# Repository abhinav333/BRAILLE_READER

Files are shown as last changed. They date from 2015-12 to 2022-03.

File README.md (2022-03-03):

# Braille e-book reader

Refer work *A. Kulkarni and K. Bhurchandi, "Low Cost E-Book Reading Device for Blind People," 2015 International Conference on Computing Communication Control and Automation, 2015, pp. 516-520, doi: 10.1109/ICCUBEA.2015.106.*

Program, schematics and images<br />
File description:<br />
**braillecode.c** - Lookup table for mapping of aplhanumeric characters to respective braille characters<br />
**buzzer.c** - Contains modules to generate variety of buzzer notifications<br />
**lcd.c** - Consists of lcd display functions. Used only in test mode.<br />
**main.c** - Main program<br />
**mmc.c** - PetitFATFS library: MMC Disk image control modules<br />
**pff.c** - PetitFATFS library: High level SD Card control modules<br />
**pffconf.h** - PetitFATFS library: Version and configuration file<br />
**spi.h** - Low level SPI access functions<br />
**Schematics** - Eagle PCB design files<br />
**test cell** - Contains debug modules for each braille cell<br />
**Hardware** - Device images<br />

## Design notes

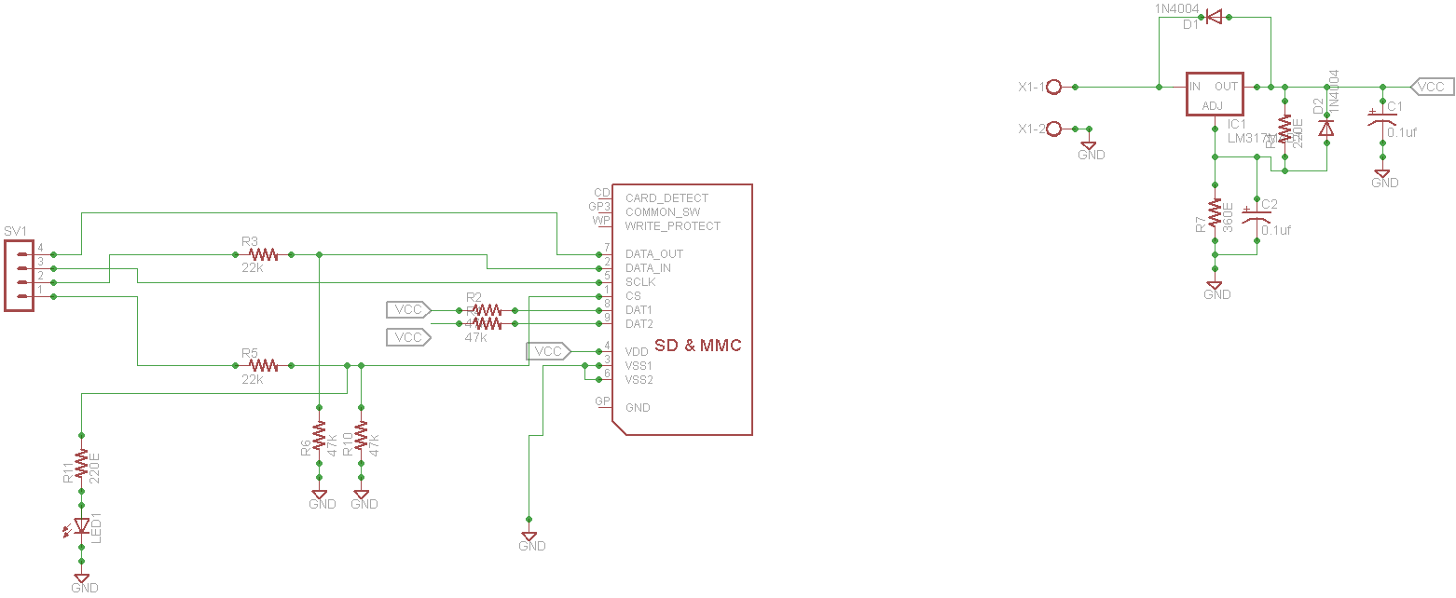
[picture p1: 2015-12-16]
schematics/sdunitckt.png

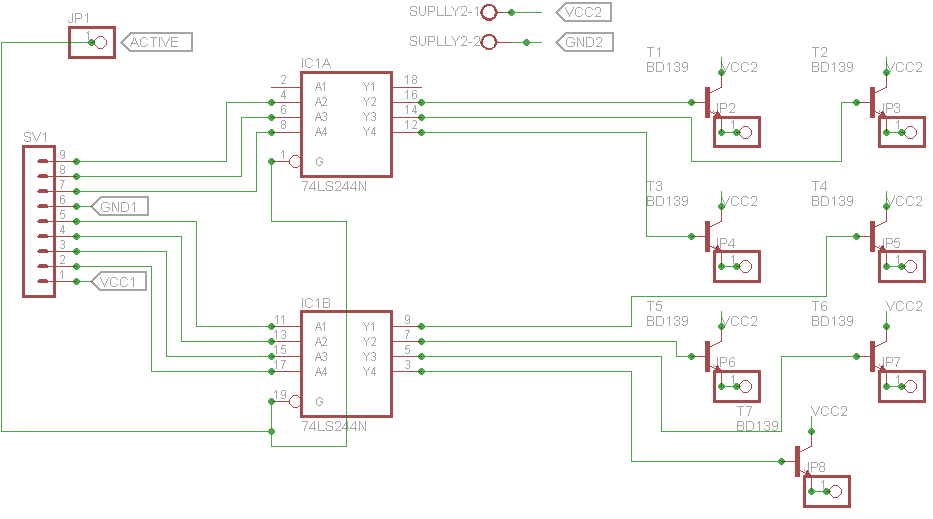
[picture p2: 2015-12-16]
schematics/driverckt.png

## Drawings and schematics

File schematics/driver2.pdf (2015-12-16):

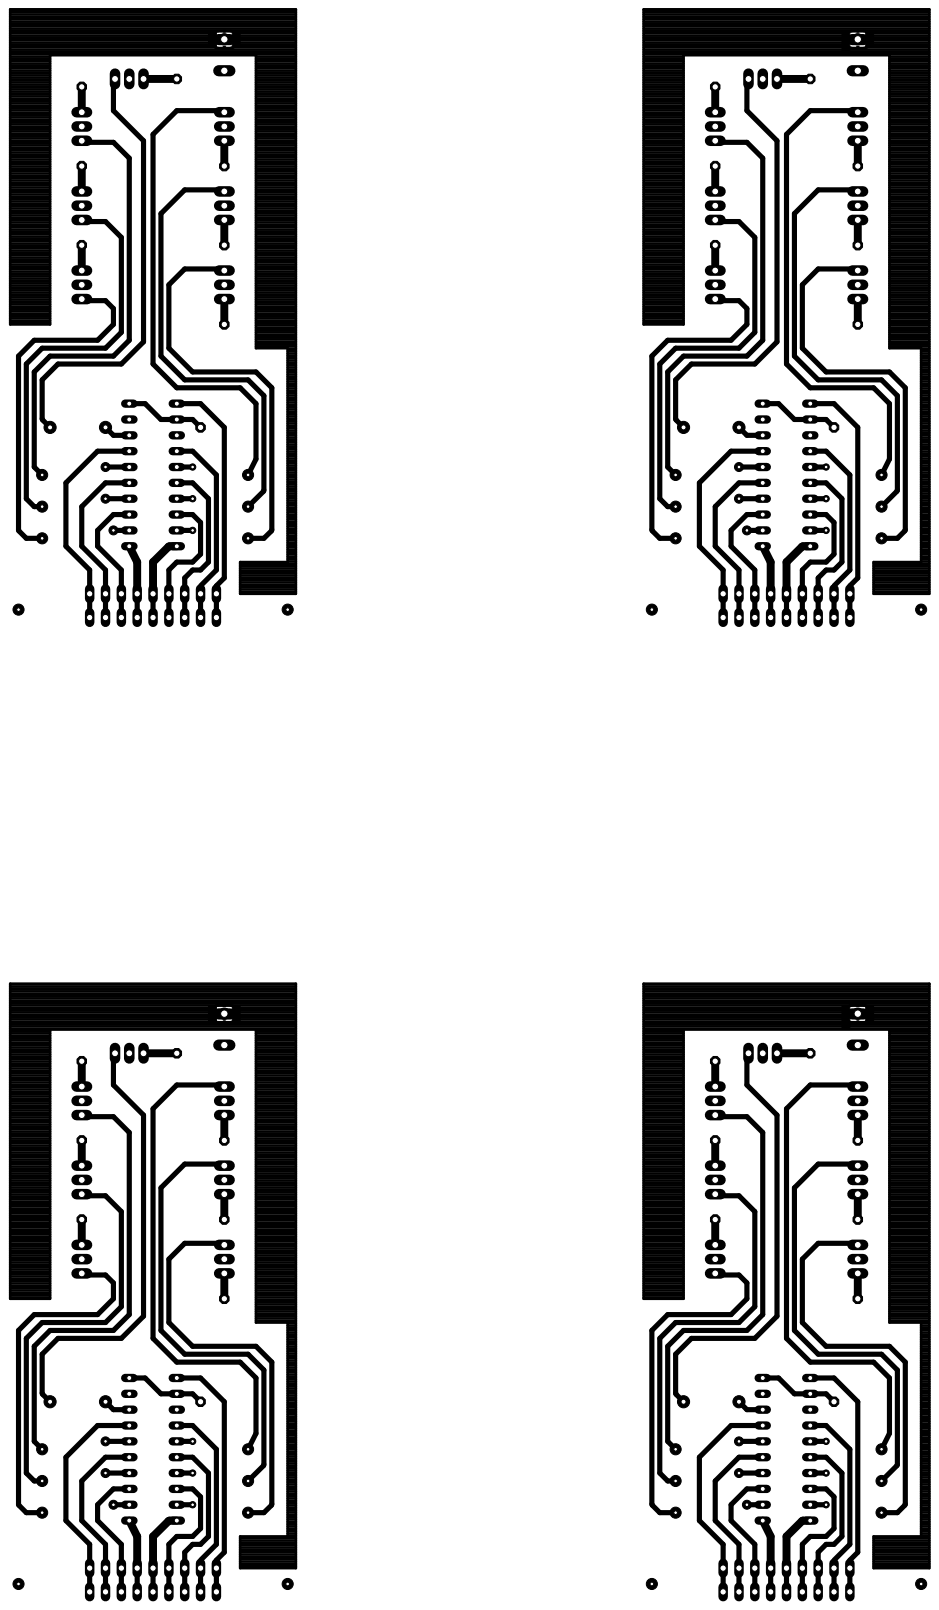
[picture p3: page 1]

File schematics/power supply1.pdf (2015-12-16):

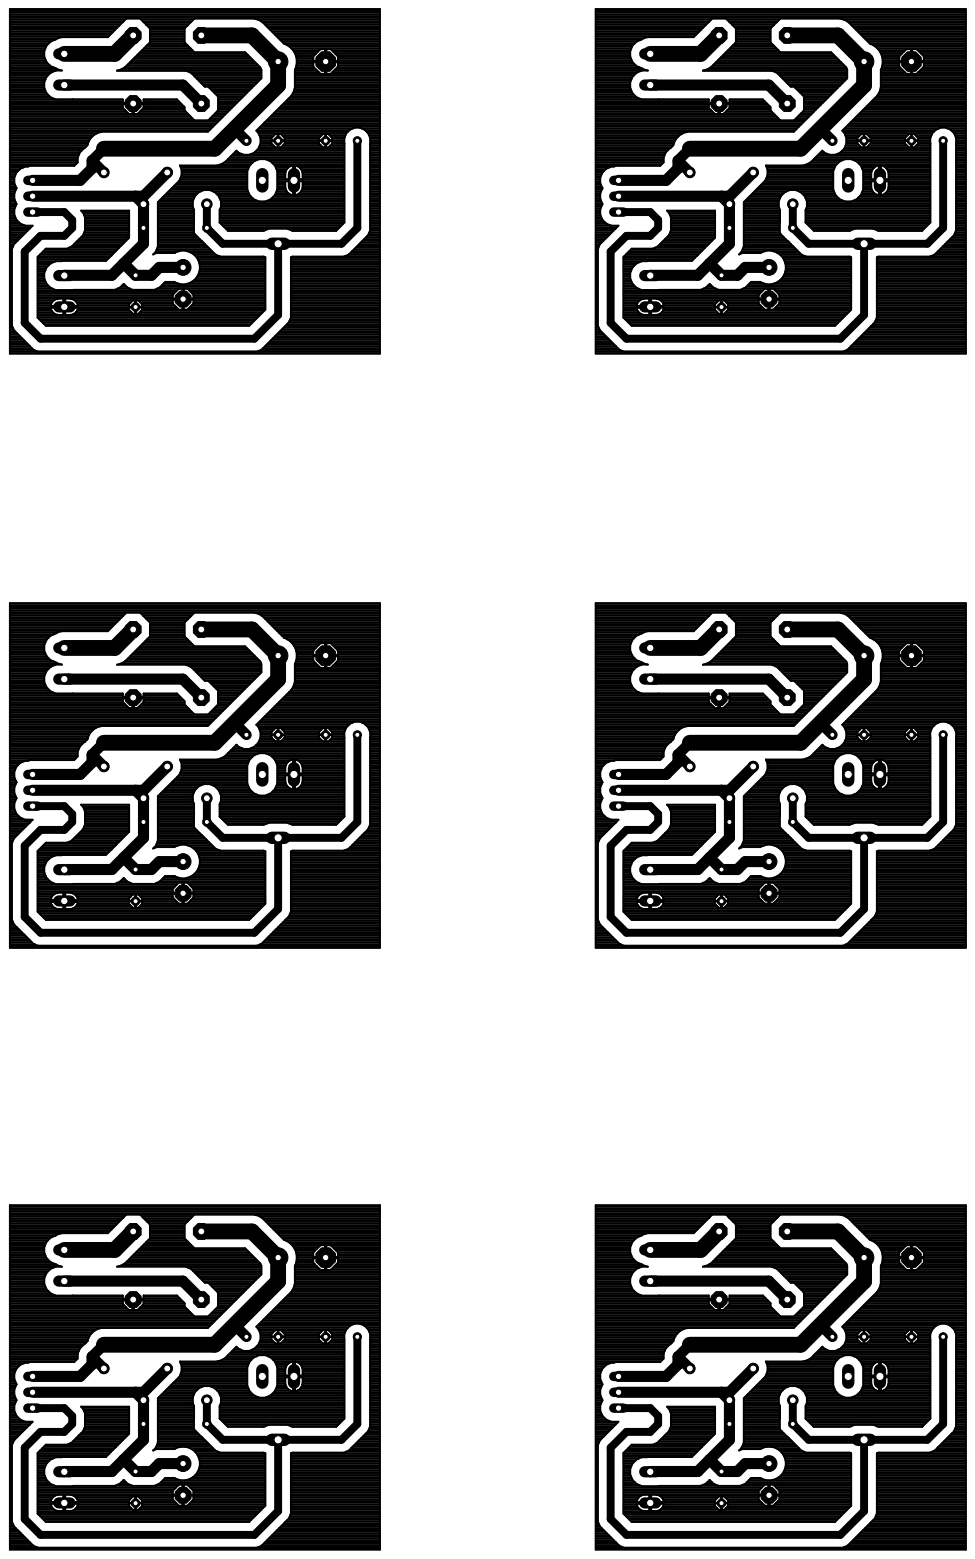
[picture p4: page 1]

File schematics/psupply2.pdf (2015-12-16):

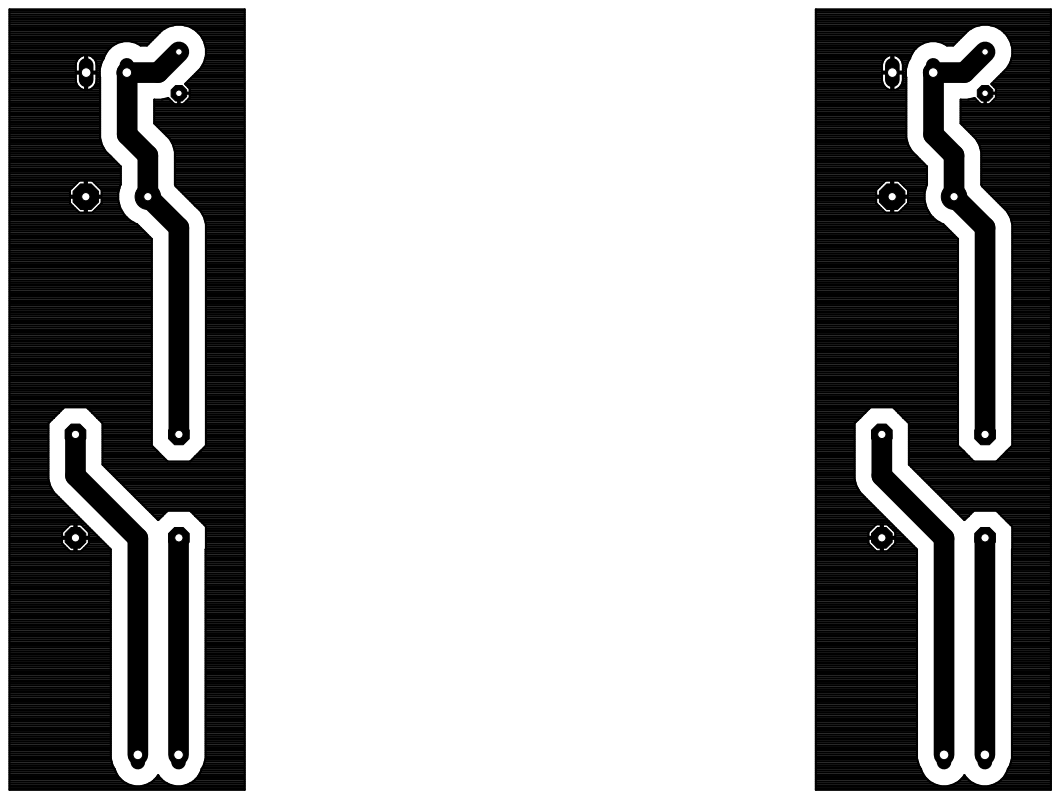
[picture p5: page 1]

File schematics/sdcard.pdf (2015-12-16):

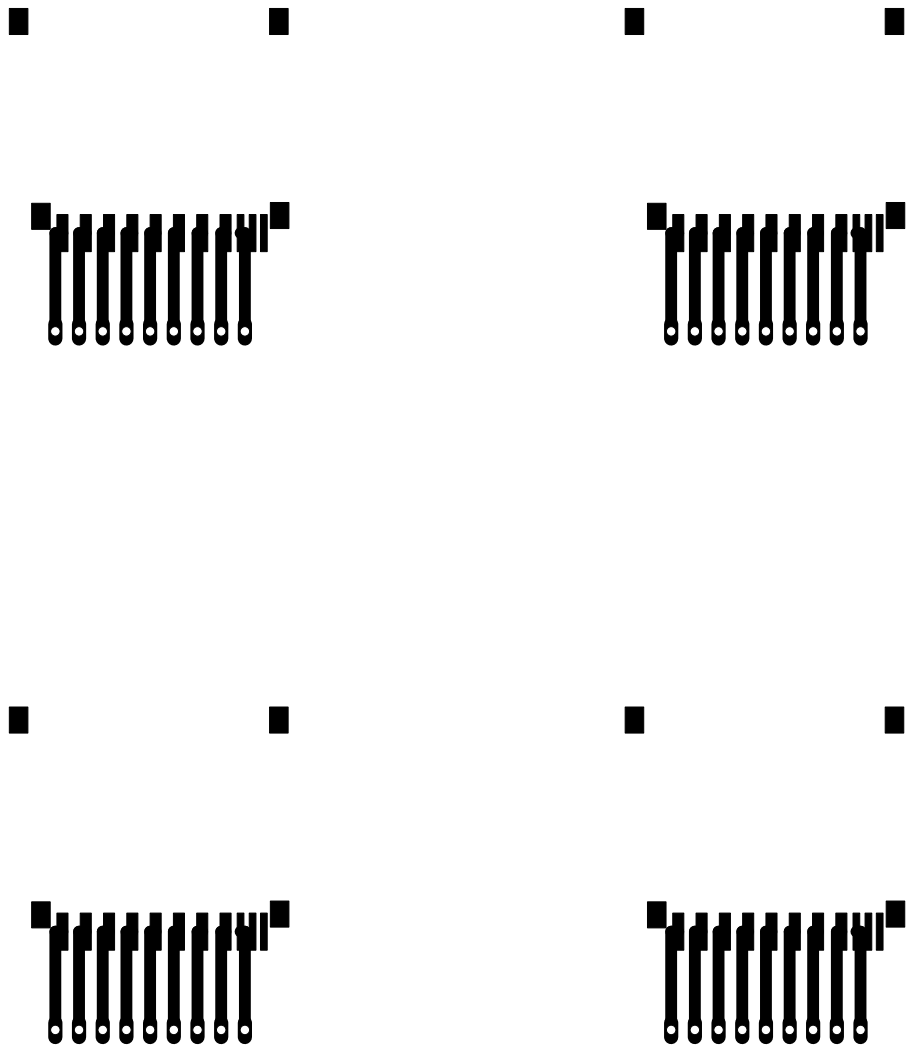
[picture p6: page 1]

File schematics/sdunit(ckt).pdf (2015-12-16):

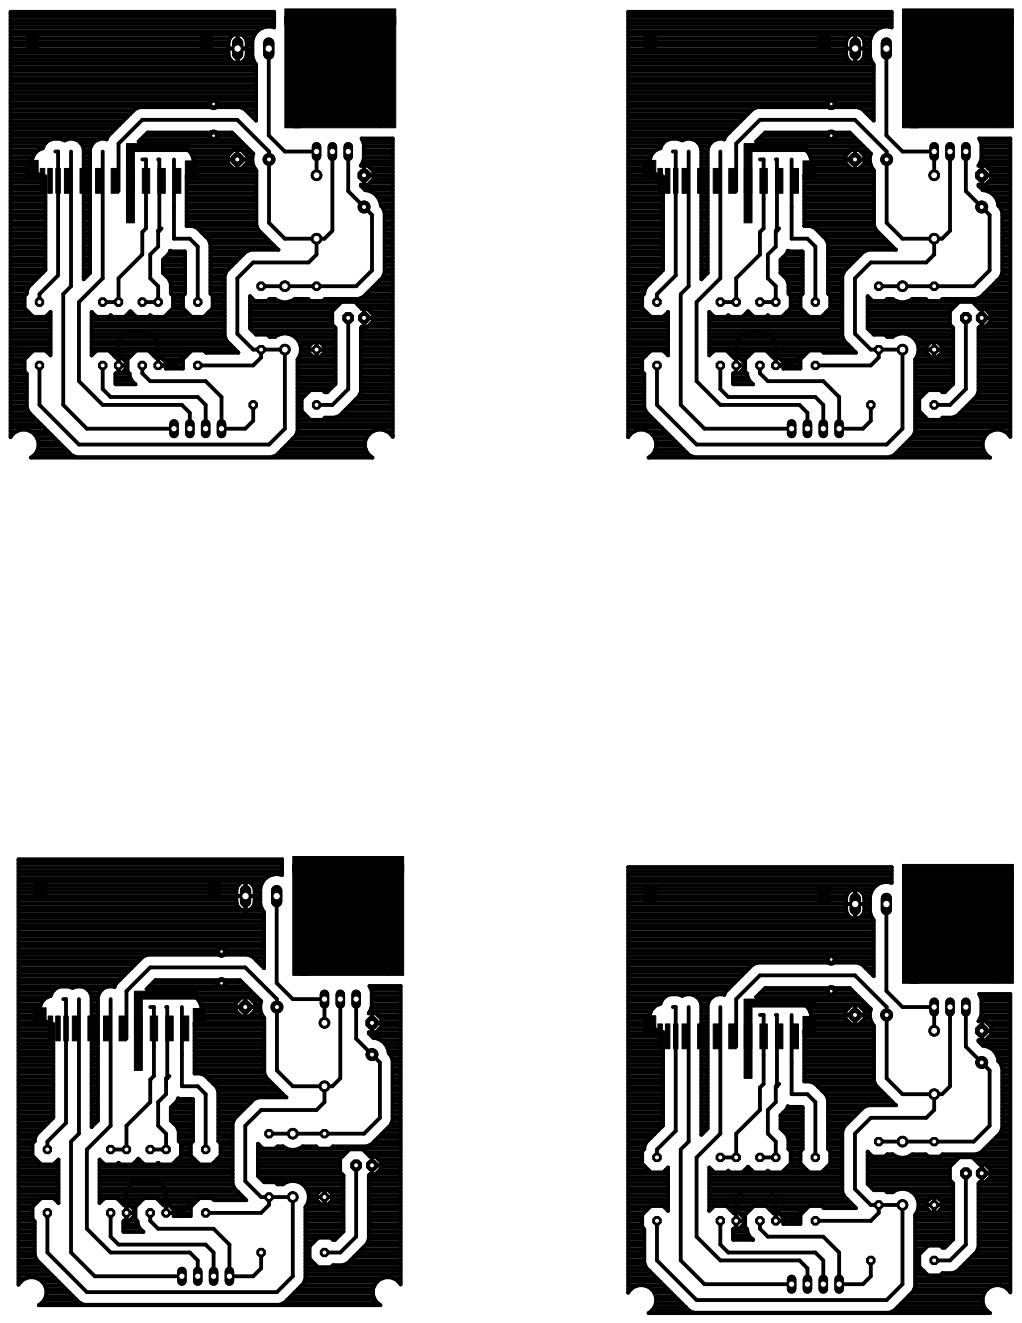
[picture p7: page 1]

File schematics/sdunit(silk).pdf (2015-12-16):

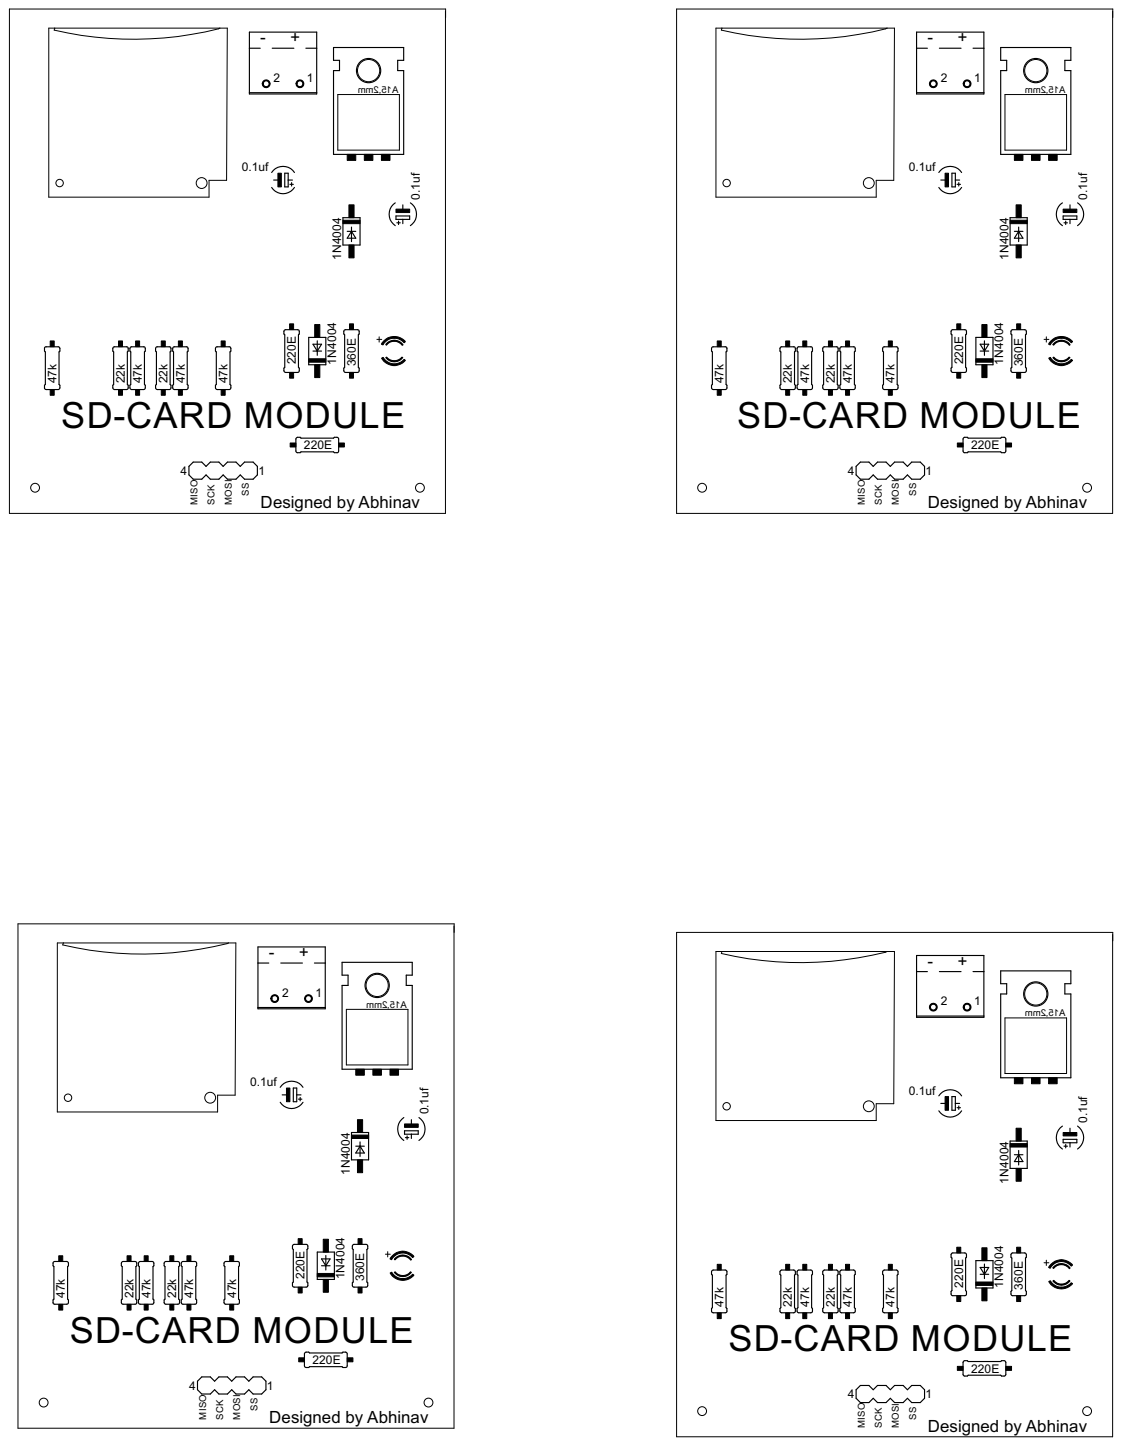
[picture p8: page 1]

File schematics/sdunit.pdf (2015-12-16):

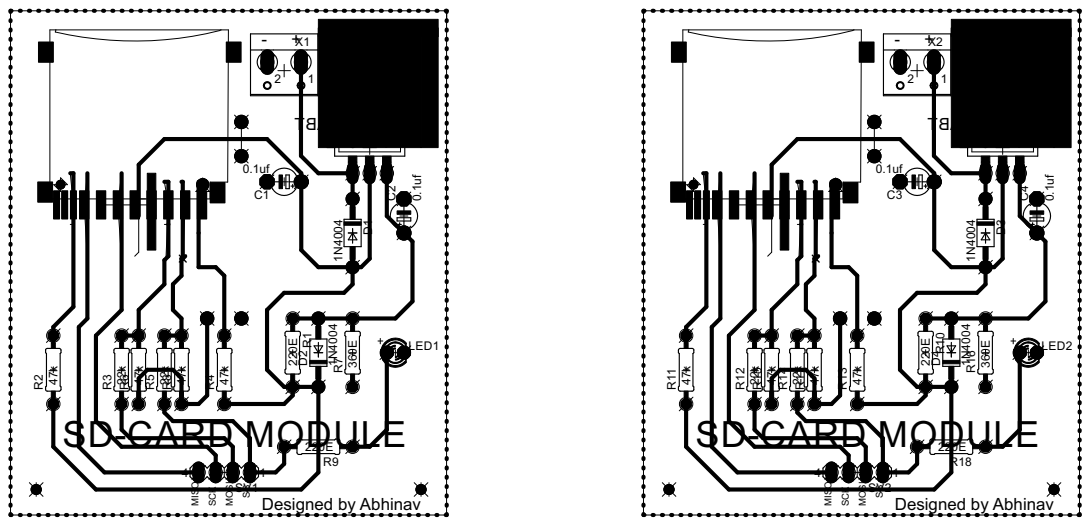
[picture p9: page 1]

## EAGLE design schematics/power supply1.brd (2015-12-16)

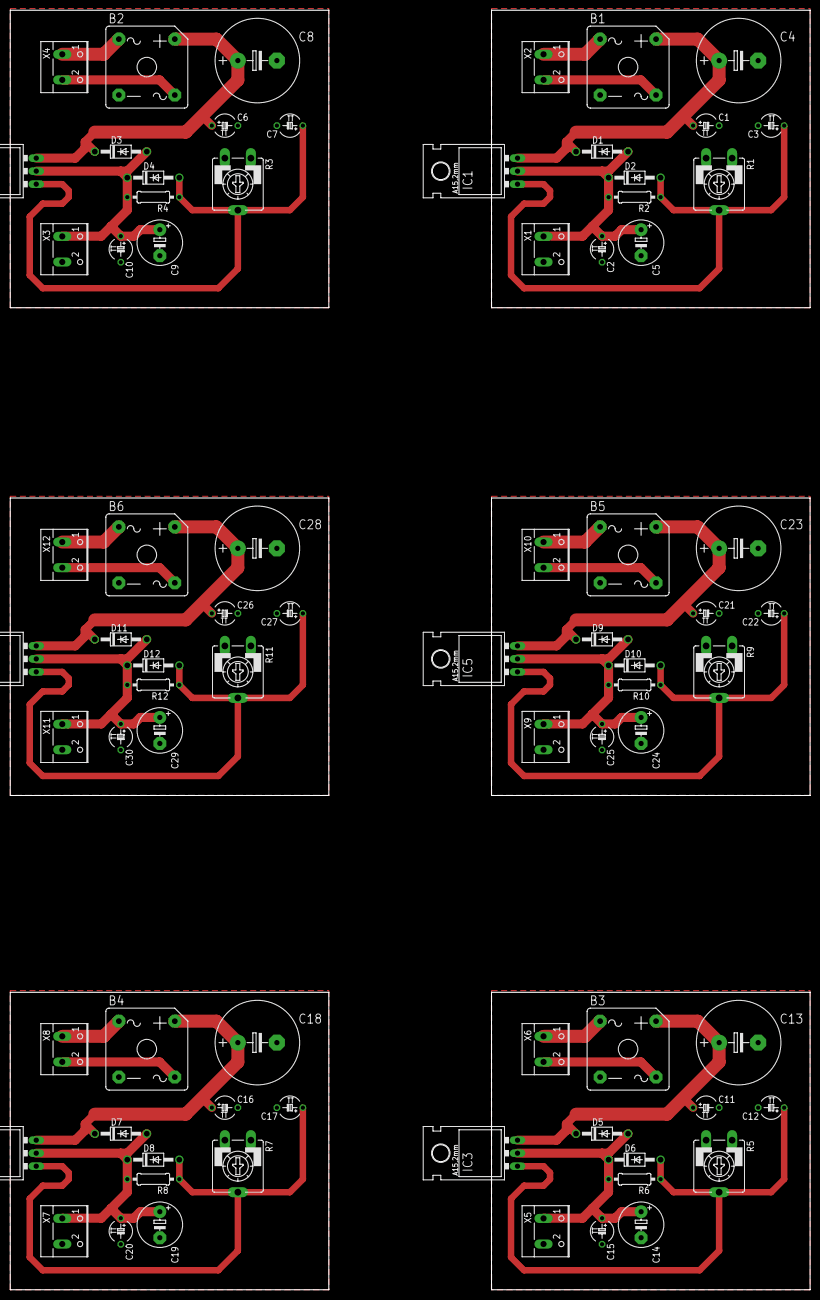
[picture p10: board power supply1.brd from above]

Board: 2 copper layers, 156.2 x 249.9 mm, 78 parts (0 on the bottom side), 36 nets.

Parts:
B1, B2, B3, B4, B5, B6: GBPC1
C1, C2, C3, C6, C7, C10, C11, C12, C15, C16, C17, C20, C21, C22, C25, C26, C27, C30: 0.1uF; TAP5-45
C4, C8, C13, C18, C23, C28: E7,5-16
C5, C9, C14, C19, C24, C29: E5-8,5
D1, D2, D3, D4, D5, D6, D7, D8, D9, D10, D11, D12: 1N4004; DO41-10
IC1, IC2, IC3, IC4, IC5, IC6: LM317MBT; TO220L1
R1, R3, R5, R7, R9, R11: CA9V
R2, R4, R6, R8, R10, R12: 120R; 0207/10
X1, X2, X3, X4, X5, X6, X7, X8, X9, X10, X11, X12: W237-102

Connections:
AGND: B1.-, C1.-, C2.-, C3.-, C4.-, C5.-, R1.A, X1.2
AGND1: B2.-, C6.-, C7.-, C8.-, C9.-, C10.-, R3.A, X3.2
AGND2: B3.-, C11.-, C12.-, C13.-, C14.-, C15.-, R5.A, X5.2
AGND3: B4.-, C16.-, C17.-, C18.-, C19.-, C20.-, R7.A, X7.2
AGND4: B5.-, C21.-, C22.-, C23.-, C24.-, C25.-, R9.A, X9.2
AGND5: B6.-, C26.-, C27.-, C28.-, C29.-, C30.-, R11.A, X11.2
unnamed: B1.+, C1.+, C4.+, D1.C, IC1.3
unnamed: C2.+, C5.+, D1.A, D2.C, IC1.2, R2.2, X1.1
unnamed: C3.+, D2.A, IC1.1, R1.S, R2.1
unnamed: B2.+, C6.+, C8.+, D3.C, IC2.3
unnamed: C9.+, C10.+, D3.A, D4.C, IC2.2, R4.2, X3.1
unnamed: B1.AC1, X2.1
unnamed: B1.AC2, X2.2
unnamed: C7.+, D4.A, IC2.1, R3.S, R4.1
unnamed: B2.AC1, X4.1
unnamed: B2.AC2, X4.2
unnamed: B3.+, C11.+, C13.+, D5.C, IC3.3
unnamed: C14.+, C15.+, D5.A, D6.C, IC3.2, R6.2, X5.1
unnamed: C12.+, D6.A, IC3.1, R5.S, R6.1
unnamed: B3.AC1, X6.1
unnamed: B3.AC2, X6.2
unnamed: B4.+, C16.+, C18.+, D7.C, IC4.3
unnamed: C19.+, C20.+, D7.A, D8.C, IC4.2, R8.2, X7.1
unnamed: C17.+, D8.A, IC4.1, R7.S, R8.1
unnamed: B4.AC1, X8.1
unnamed: B4.AC2, X8.2
unnamed: B5.+, C21.+, C23.+, D9.C, IC5.3
unnamed: C24.+, C25.+, D9.A, D10.C, IC5.2, R10.2, X9.1
unnamed: C22.+, D10.A, IC5.1, R9.S, R10.1
unnamed: B5.AC1, X10.1
unnamed: B5.AC2, X10.2
unnamed: B6.+, C26.+, C28.+, D11.C, IC6.3
unnamed: C29.+, C30.+, D11.A, D12.C, IC6.2, R12.2, X11.1
unnamed: C27.+, D12.A, IC6.1, R11.S, R12.1
unnamed: B6.AC1, X12.1
unnamed: B6.AC2, X12.2

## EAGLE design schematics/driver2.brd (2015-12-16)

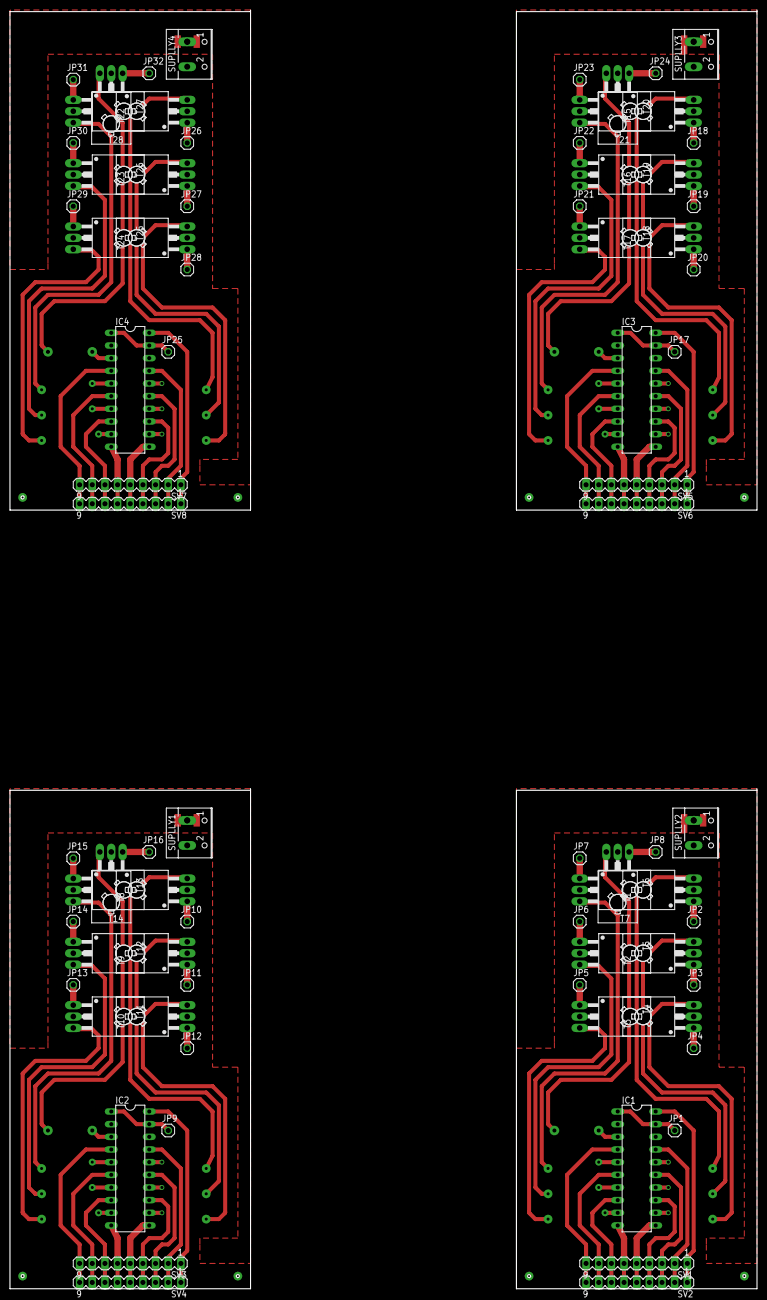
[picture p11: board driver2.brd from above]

Board: 2 copper layers, 149.9 x 256.5 mm, 76 parts (0 on the bottom side), 96 nets.

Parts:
IC1, IC2, IC3, IC4: 74LS244N; DIL20
JP1, JP2, JP3, JP4, JP5, JP6, JP7, JP8, JP9, JP10, JP11, JP12, JP13, JP14, JP15, JP16, JP17, JP18, JP19, JP20, JP21, JP22, JP23, JP24, JP25, JP26, JP27, JP28, JP29, JP30, JP31, JP32: 1X01
SUPLLY1, SUPLLY2, SUPLLY3, SUPLLY4: W237-102
SV1, SV2, SV3, SV4, SV5, SV6, SV7, SV8: MA09-1
T1, T2, T3, T4, T5, T6, T7, T8, T9, T10, T11, T12, T13, T14, T15, T16, T17, T18, T19, T20, T21, T22, T23, T24, T25, T26, T27, T28: BD139; TO126

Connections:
ACTIVE: IC1.1, IC1.19, JP1.1
ACTIVE1: IC2.1, IC2.19, JP9.1
ACTIVE2: IC3.1, IC3.19, JP17.1
ACTIVE3: IC4.1, IC4.19, JP25.1
GND1: IC1.10, SV1.6, SV2.6
GND4: IC2.10, SV3.6, SV4.6
GND6: IC3.10, SV5.6, SV6.6
GND8: IC4.10, SV7.6, SV8.6
unnamed: IC1.4, SV1.9, SV2.9
unnamed: IC1.6, SV1.8, SV2.8
unnamed: IC1.8, SV1.7, SV2.7
unnamed: IC1.3, T7.3
unnamed: IC1.11, SV1.5, SV2.5
unnamed: IC1.13, SV1.4, SV2.4
unnamed: IC1.16, T1.3
unnamed: JP2.1, T1.1
unnamed: IC1.14, T2.3
unnamed: IC1.12, T3.3
unnamed: IC1.15, SV1.3, SV2.3
unnamed: IC1.9, T4.3
unnamed: IC1.7, T5.3
unnamed: JP3.1, T2.1
unnamed: JP4.1, T3.1
unnamed: JP5.1, T4.1
unnamed: JP6.1, T5.1
unnamed: JP7.1, T6.1
unnamed: JP8.1, T7.1
unnamed: IC1.17, SV1.2, SV2.2
unnamed: IC2.12, T10.3
unnamed: JP10.1, T8.1
unnamed: JP11.1, T9.1
unnamed: JP12.1, T10.1
unnamed: JP13.1, T11.1
unnamed: JP14.1, T12.1
unnamed: JP15.1, T13.1
unnamed: JP16.1, T14.1
unnamed: IC2.3, T14.3
unnamed: IC2.16, T8.3
unnamed: IC2.14, T9.3
unnamed: IC2.9, T11.3
unnamed: IC2.7, T12.3
unnamed: IC2.4, SV3.9, SV4.9
unnamed: IC2.6, SV3.8, SV4.8
unnamed: IC2.8, SV3.7, SV4.7
unnamed: IC2.11, SV3.5, SV4.5
unnamed: IC2.13, SV3.4, SV4.4
unnamed: IC2.15, SV3.3, SV4.3
unnamed: IC2.17, SV3.2, SV4.2
unnamed: IC3.12, T17.3
unnamed: JP18.1, T15.1
unnamed: JP19.1, T16.1
unnamed: JP20.1, T17.1
unnamed: JP21.1, T18.1
unnamed: JP22.1, T19.1
unnamed: JP23.1, T20.1
unnamed: JP24.1, T21.1
unnamed: IC3.3, T21.3
unnamed: IC3.16, T15.3
unnamed: IC3.14, T16.3
unnamed: IC3.9, T18.3
unnamed: IC3.7, T19.3
unnamed: IC3.4, SV5.9, SV6.9
unnamed: IC3.6, SV5.8, SV6.8
unnamed: IC3.8, SV5.7, SV6.7
unnamed: IC3.11, SV5.5, SV6.5
unnamed: IC3.13, SV5.4, SV6.4
unnamed: IC3.15, SV5.3, SV6.3
unnamed: IC3.17, SV5.2, SV6.2
unnamed: IC4.12, T24.3
unnamed: JP26.1, T22.1
unnamed: JP27.1, T23.1
unnamed: JP28.1, T24.1
unnamed: JP29.1, T25.1
unnamed: JP30.1, T26.1
unnamed: JP31.1, T27.1
unnamed: JP32.1, T28.1
unnamed: IC4.3, T28.3
unnamed: IC4.16, T22.3
unnamed: IC4.14, T23.3
unnamed: IC4.9, T25.3
unnamed: IC4.7, T26.3
unnamed: IC4.4, SV7.9, SV8.9
unnamed: IC4.6, SV7.8, SV8.8
unnamed: IC4.8, SV7.7, SV8.7
unnamed: IC4.11, SV7.5, SV8.5
unnamed: IC4.13, SV7.4, SV8.4
unnamed: IC4.15, SV7.3, SV8.3
unnamed: IC4.17, SV7.2, SV8.2
VCC1: IC1.20, SV1.1, SV2.1
VCC2: SUPLLY2.1, T1.2, T2.2, T3.2
VCC3: SUPLLY1.1, T8.2, T9.2, T10.2
VCC4: IC2.20, SV3.1, SV4.1
VCC5: SUPLLY3.1, T15.2, T16.2, T17.2
VCC6: IC3.20, SV5.1, SV6.1
VCC7: SUPLLY4.1, T22.2, T23.2, T24.2
VCC8: IC4.20, SV7.1, SV8.1

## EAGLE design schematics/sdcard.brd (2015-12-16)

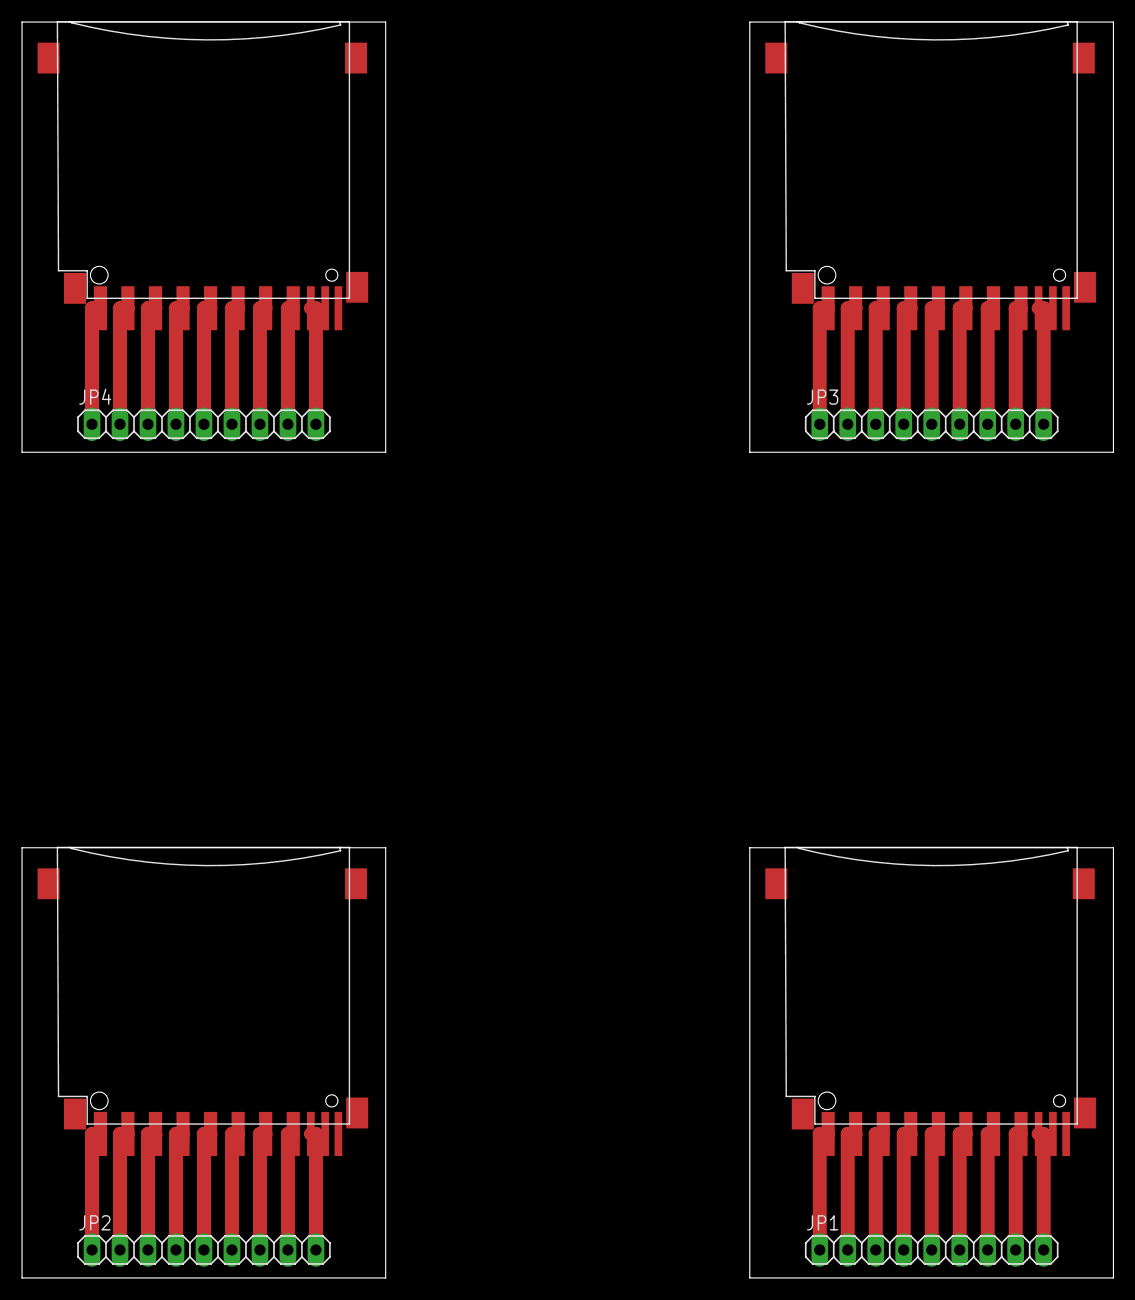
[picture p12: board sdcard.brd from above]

Board: 2 copper layers, 99.0 x 114.0 mm, 8 parts (0 on the bottom side), 36 nets.

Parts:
JP1, JP2, JP3, JP4: 1X09
U$1, U$2, U$3, U$4: SDMMC06132; 06132

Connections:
unnamed: JP1.2, U$1.1
unnamed: JP1.1, U$1.9
unnamed: JP1.3, U$1.2
unnamed: JP1.6, U$1.5
unnamed: JP1.8, U$1.7
unnamed: JP1.9, U$1.8
unnamed: JP2.2, U$2.1
unnamed: JP2.1, U$2.9
unnamed: JP2.3, U$2.2
unnamed: JP2.6, U$2.5
unnamed: JP2.8, U$2.7
unnamed: JP2.9, U$2.8
unnamed: JP3.2, U$3.1
unnamed: JP3.1, U$3.9
unnamed: JP3.3, U$3.2
unnamed: JP3.6, U$3.5
unnamed: JP3.8, U$3.7
unnamed: JP3.9, U$3.8
unnamed: JP4.2, U$4.1
unnamed: JP4.1, U$4.9
unnamed: JP4.3, U$4.2
unnamed: JP4.6, U$4.5
unnamed: JP4.8, U$4.7
unnamed: JP4.9, U$4.8
VDD: JP1.5, U$1.4
VDD1: JP2.5, U$2.4
VDD2: JP3.5, U$3.4
VDD3: JP4.5, U$4.4
VSS1: JP1.4, U$1.3
VSS2: JP1.7, U$1.6
VSS3: JP2.4, U$2.3
VSS4: JP2.7, U$2.6
VSS5: JP3.4, U$3.3
VSS6: JP3.7, U$3.6
VSS7: JP4.4, U$4.3
VSS8: JP4.7, U$4.6

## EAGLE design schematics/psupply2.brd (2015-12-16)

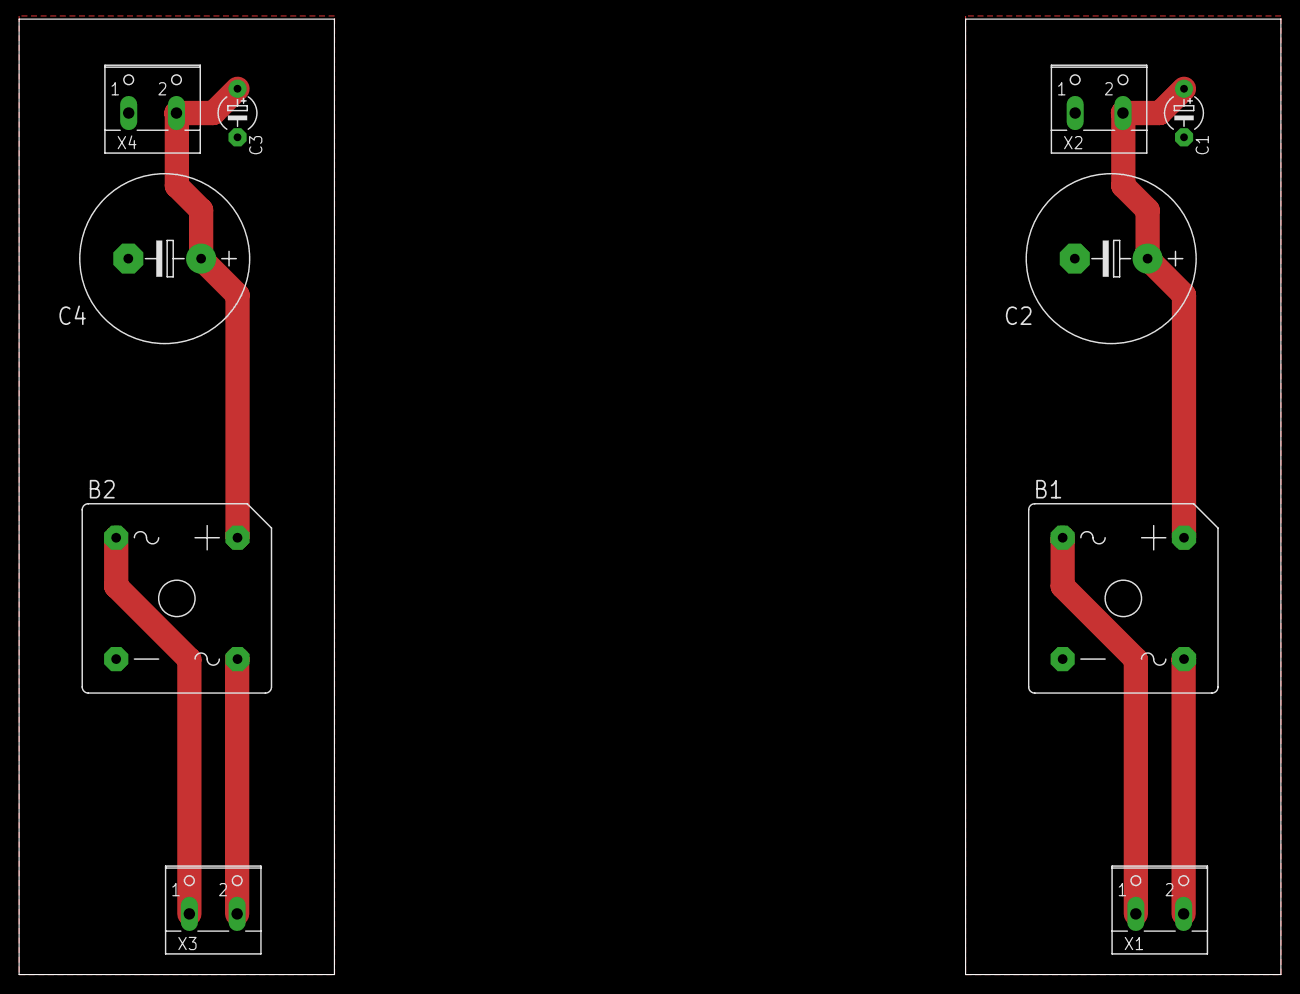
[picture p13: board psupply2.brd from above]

Board: 2 copper layers, 132.1 x 100.0 mm, 10 parts (0 on the bottom side), 8 nets.

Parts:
B1, B2: GBPC80X
C1, C3: E5-4
C2, C4: E7,5-18
X1, X2, X3, X4: W237-102

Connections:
GND: B1.-, C1.-, C2.-, X2.1
GND1: B2.-, C3.-, C4.-, X4.1
unnamed: B1.AC1, X1.1
unnamed: B1.AC2, X1.2
unnamed: B1.+, C1.+, C2.+, X2.2
unnamed: B2.AC1, X3.1
unnamed: B2.AC2, X3.2
unnamed: B2.+, C3.+, C4.+, X4.2

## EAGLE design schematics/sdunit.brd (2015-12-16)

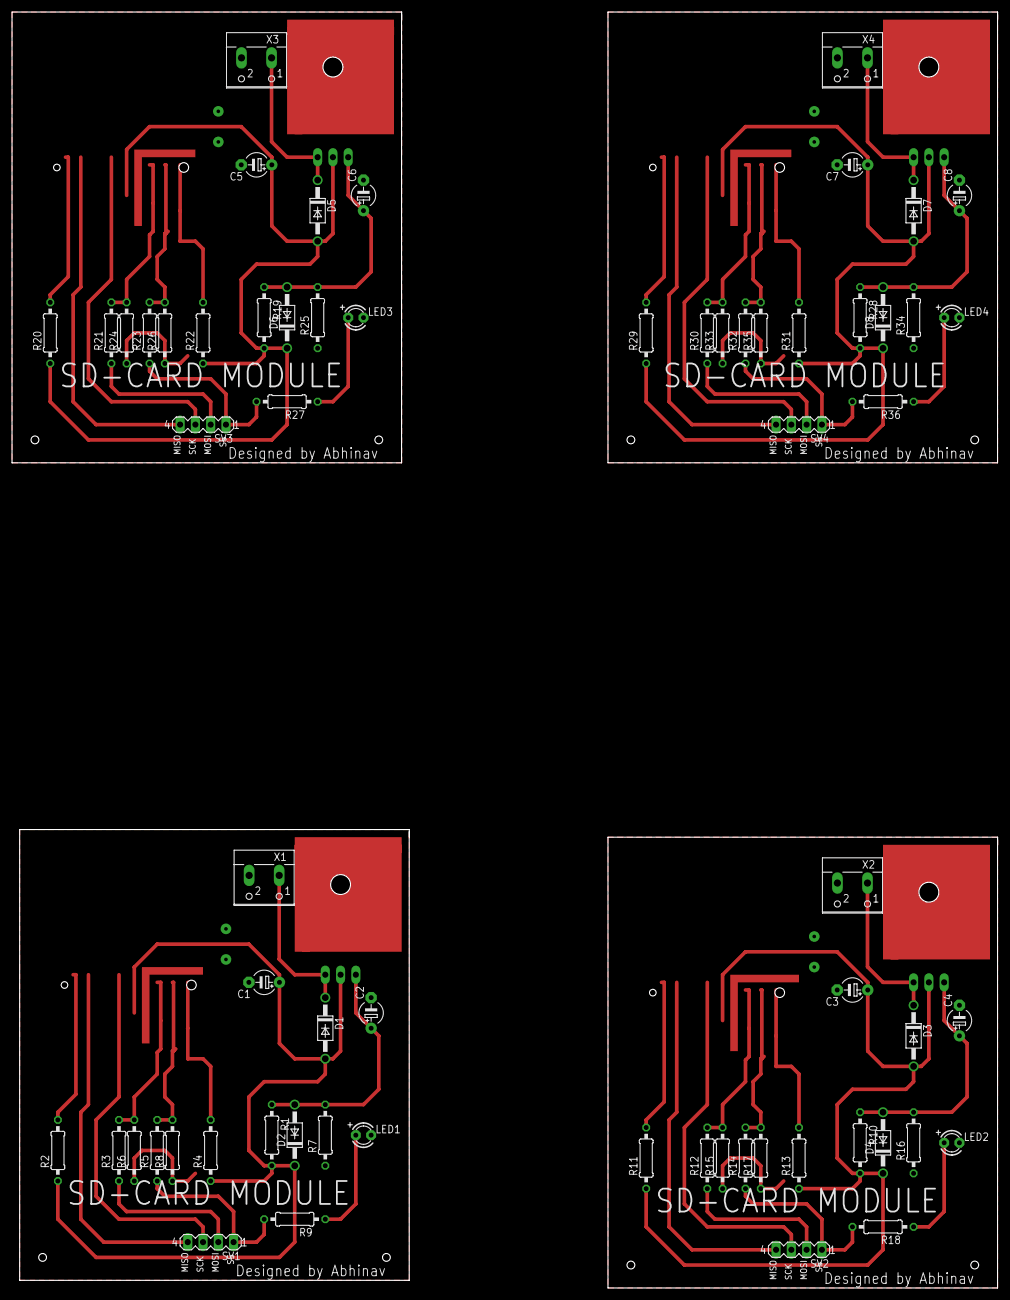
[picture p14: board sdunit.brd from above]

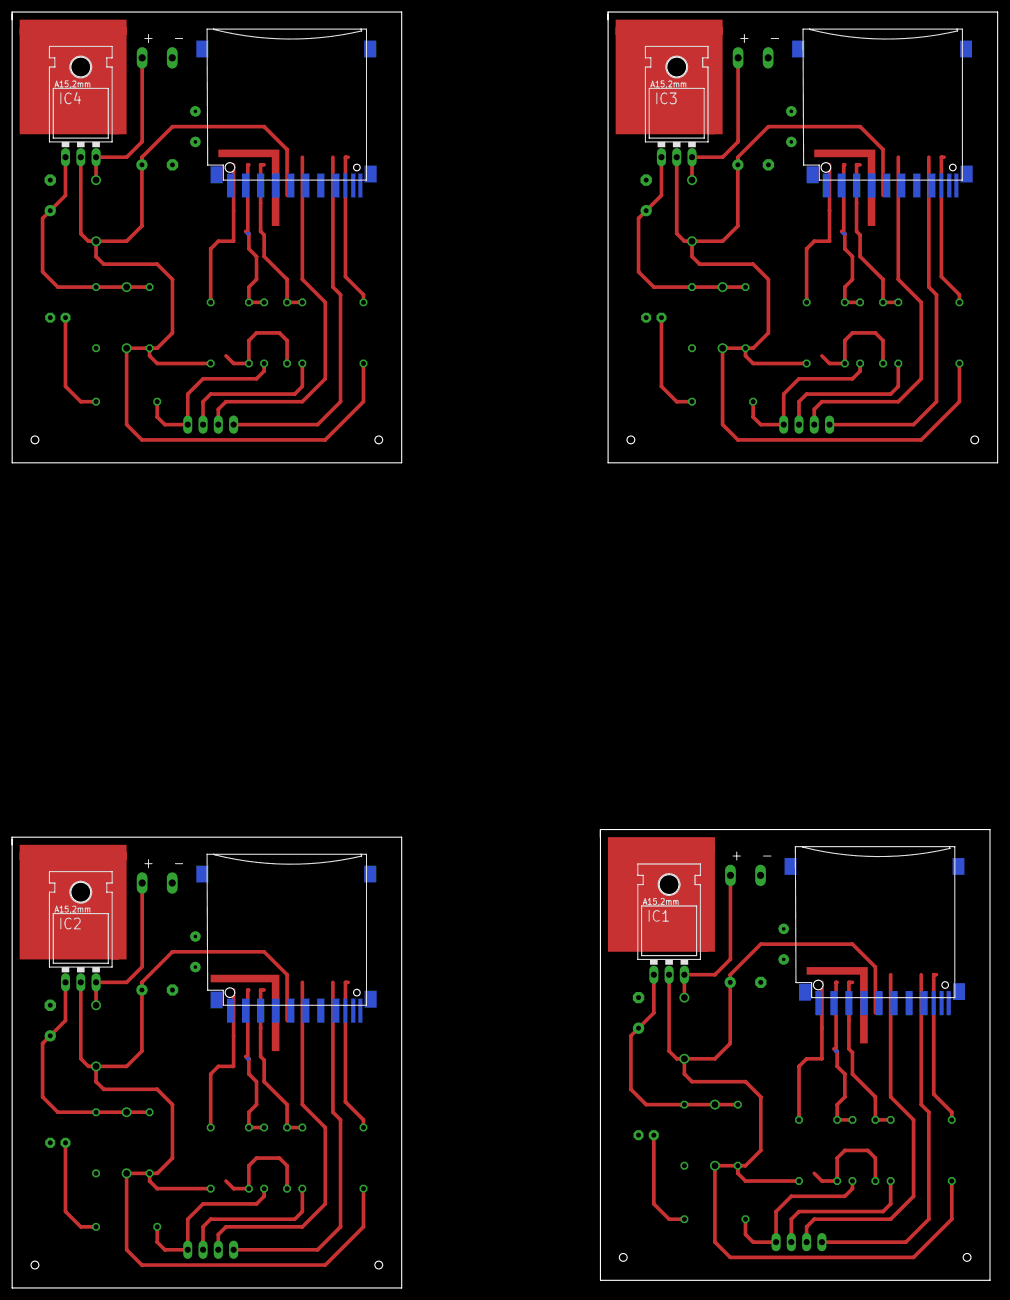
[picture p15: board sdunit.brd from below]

Board: 2 copper layers, 163.8 x 212.1 mm, 72 parts (8 on the bottom side), 56 nets.

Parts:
C1, C2, C3, C4, C5, C6, C7, C8: 0.1uf; E5-4
D1, D2, D3, D4, D5, D6, D7, D8: 1N4004; DO41-10
IC1, IC2, IC3, IC4: LM317MABT; TO220L1
LED1, LED2, LED3, LED4: LED3MM
R1, R9, R10, R18, R19, R27, R28, R36: 220E; 0207/10
R2, R4, R6, R8, R11, R13, R15, R17, R20, R22, R24, R26, R29, R31, R33, R35: 47k; 0207/10
R3, R5, R12, R14, R21, R23, R30, R32: 22k; 0207/10
R7, R16, R25, R34: 360E; 0207/10
SV1, SV2, SV3, SV4: MA04-1
U$1, U$2, U$3, U$4: SDMMC06132; 06132
X1, X2, X3, X4: W237-102

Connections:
GND1: C1.-, C2.-, LED1.K, R6.1, R7.1, R8.1, X1.2
GND2: C3.-, C4.-, LED2.K, R15.1, R16.1, R17.1, X2.2
GND3: C5.-, C6.-, LED3.K, R24.1, R25.1, R26.1, X3.2
GND4: C7.-, C8.-, LED4.K, R33.1, R34.1, R35.1, X4.2
unnamed: D1.C, IC1.3, X1.1
unnamed: C2.+, D2.A, IC1.1, R1.1, R7.2
unnamed: R3.2, R6.2, U$1.2
unnamed: R5.1, R9.2, SV1.1
unnamed: R5.2, R8.2, U$1.1
unnamed: SV1.4, U$1.7
unnamed: R2.2, U$1.8
unnamed: R4.2, U$1.9
unnamed: R3.1, SV1.2
unnamed: SV1.3, U$1.5
unnamed: D3.C, IC2.3, X2.1
unnamed: C4.+, D4.A, IC2.1, R10.1, R16.2
unnamed: R12.2, R15.2, U$2.2
unnamed: R14.1, R18.2, SV2.1
unnamed: R14.2, R17.2, U$2.1
unnamed: SV2.4, U$2.7
unnamed: R11.2, U$2.8
unnamed: R13.2, U$2.9
unnamed: R12.1, SV2.2
unnamed: SV2.3, U$2.5
unnamed: D5.C, IC3.3, X3.1
unnamed: C6.+, D6.A, IC3.1, R19.1, R25.2
unnamed: R21.2, R24.2, U$3.2
unnamed: R23.1, R27.2, SV3.1
unnamed: R23.2, R26.2, U$3.1
unnamed: SV3.4, U$3.7
unnamed: R20.2, U$3.8
unnamed: R22.2, U$3.9
unnamed: R21.1, SV3.2
unnamed: SV3.3, U$3.5
unnamed: D7.C, IC4.3, X4.1
unnamed: C8.+, D8.A, IC4.1, R28.1, R34.2
unnamed: R30.2, R33.2, U$4.2
unnamed: R32.1, R36.2, SV4.1
unnamed: R32.2, R35.2, U$4.1
unnamed: SV4.4, U$4.7
unnamed: R29.2, U$4.8
unnamed: R31.2, U$4.9
unnamed: R30.1, SV4.2
unnamed: SV4.3, U$4.5
S$1: LED2.A, R18.1
S$2: LED1.A, R9.1
S$3: LED3.A, R27.1
S$4: LED4.A, R36.1
VCC1: C1.+, D1.A, D2.C, IC1.2, R1.2, R2.1, R4.1, U$1.4
VCC2: C3.+, D3.A, D4.C, IC2.2, R10.2, R11.1, R13.1, U$2.4
VCC3: C5.+, D5.A, D6.C, IC3.2, R19.2, R20.1, R22.1, U$3.4
VCC4: C7.+, D7.A, D8.C, IC4.2, R28.2, R29.1, R31.1, U$4.4
VSS1: U$1.3, U$1.6
VSS2: U$2.3, U$2.6
VSS3: U$3.3, U$3.6
VSS4: U$4.3, U$4.6

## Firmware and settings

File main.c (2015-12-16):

#include <avr/io.h>
#include <util/delay.h>
#include <avr/interrupt.h>
#include <avr/wdt.h>
#include<string.h>
#define F_CPU 8000000
#include "integer.h"

#include "pff.h"
#include "pff.c"
//#include"lcd.h"
//#include"lcd.c"
#include"diskio.h"
#include"mmc.c"
#include"buzzer.c"
#include"braillecode.c"


#define FORWARD 1
#define BACKWARD 2
#define PAUSE 3
#define STATE0 0
#define STATE1 1
#define NCHANGE 0
#define CHANGE 1
#define START 0
#define END 1


unsigned int chk_button()
{
 
 if(!(PIND & 0x01))
 {
   
   
   //_delay_ms(170);
   return FORWARD;
 
   

 }
 if(!(PIND & 0x02))
 {
  	
 	//_delay_ms(170);
   return BACKWARD;
	
	

 
 }


 if(!(PIND & 0x08))
 {
   
	
	 //_delay_ms(170);
	 return PAUSE;
	
	
 }
 
 return 0;

}




void getbinary(unsigned char byte11,char *binarr11)
{
 int t,i,bit11=0;
 for(i=7;i>=0;i--)
 {

  t=(int)byte11;

  t&=(1<<i);
  t>>=i;
  bit11=t ? 1 : 0;
  itoa(bit11,&binarr11[7-i],10);
 }



}


int main(void)
{
	//lcd_init(LCD_DISP_ON_CURSOR); /* initialize lcd, display on, cursor on */
                                  /* for more options for*/
    BYTE buf11,dir_status=START;                             /* lcd_init(), view lcd.h file*/
    BYTE schange=CHANGE,state=STATE0;
    UINT bread=1;
	FATFS fs;
	BYTE buff11[8];
	FRESULT fr11='N';
	FILINFO file;
	DIR dr;
	char fpath[25];
  char try=10;;
    //lcd_clrscr();
	//lcd_home();	
	char ocr[4];
    char n=0;	
                      /* run continuously */
    
    
	//button initialization 
   DDRD=0xF0;
   
   PORTD=0x0F;
   PORTD|=0x80;
   PORTD&=~0x40;

	//braille cell init
   DDRA=0xFF;
   PORTA=0; 
	

/*

    fr11=disk_initialize();
	getbinary(fr11,buff11);
	//lcd_puts(buff11);
	_delay_ms(2000);
	//lcd_clrscr();
    //lcd_home();
	_delay_ms(2000);
	*/

/*
	
	init_spi();		
	DESELECT();
	for (n = 20; n; n--) rcv_spi();


     
	 fr11=send_cmd(CMD0, 0);
	
	getbinary(fr11,buff11);
	//lcd_puts(buff11);
	_delay_ms(2000);
	//lcd_clrscr();
    //lcd_home();
	_delay_ms(2000);
	n=10;
	while(n)
	{
     fr11=send_cmd(CMD8,0x01AA);
     n--;
	 if(fr11==1)break;
	}
	
	for (n = 0; n < 4; n++) ocr[n] = rcv_spi();	
  
	getbinary(fr11,buff11);
	//lcd_puts(buff11);
	_delay_ms(2000);
	//lcd_clrscr();
    //lcd_home();
	_delay_ms(2000);
	
  
    
  	
     getbinary(ocr[0],buff11);	  
	 //lcd_puts(buff11);
	_delay_ms(2000);
	//lcd_clrscr();
    //lcd_home();
	_delay_ms(2000);
	
	getbinary(ocr[1],buff11);	  
	//lcd_puts(buff11);
	_delay_ms(2000);
	//lcd_clrscr();
    //lcd_home();
	_delay_ms(2000);
	
	getbinary(ocr[2],buff11);	  
	//lcd_puts(buff11);
	_delay_ms(2000);
	//lcd_clrscr();
    //lcd_home();
	_delay_ms(2000);
	
	getbinary(ocr[3],buff11);	  
	//lcd_puts(buff11);
	_delay_ms(2000);
	//lcd_clrscr();
    //lcd_home();
	_delay_ms(2000);
	*/
	// Pin 7 & 6 of c act as triggers for two cell
	




	while(try)
	{
     fr11=pf_mount(&fs);
     try--;
     if(!fr11) break;    
	}
	if(fr11)
	{
     //lcd_puts("Mount Error");
	 play_buzzer(5,1,20);
      wdt_reset();
	  WDTCR=(1<<WDE) | (1<<WDP2)|(1<<WDP1)|(1<<WDP0);
	  _delay_ms(3000);
	}
	
   	
    fr11=pf_opendir(&dr,"BOOKS");
	if(fr11)
	{
		//lcd_puts("DIR Open Error");
		play_buzzer(5,3,20);
		 
	}
	 
	fr11=pf_readdir(&dr,&file);
	
	if(fr11)
	{
		//lcd_puts("DIR EXp Error");
		play_buzzer(5,5,20);
		 
	}
	//lcd_puts(file.fname);
//temporaryt
	
	play_buzzer(1,1,40);
	
	while(1)
	{
	  if(state==STATE0)
	  {
	   while(chk_button()!=PAUSE)
	   {
	     if(chk_button()==FORWARD && dir_status!=END)
        {   
	      buzzer_on();
		  _delay_ms(50);
		  buzzer_off();
		  _delay_ms(150);
		  schange=CHANGE;
		  //lcd_clrscr();
		  //lcd_home();
		  fr11=pf_readdir(&dr,&file);
	  	  if(fr11)play_buzzer(2,5,20);;
	      if(file.fname[0]==0)dir_status=END;
		  //lcd_puts(file.fname);
		  
		  	}
        if(chk_button()==BACKWARD)
        {
          buzzer_on();
		  _delay_ms(50);
		  buzzer_off();
		  _delay_ms(150);
		  dir_status=START;
		  schange=CHANGE;
		  //lcd_clrscr();
		  //lcd_home();
		  fr11=pf_readdir(&dr,0);
		  fr11=pf_readdir(&dr,&file);
		  if(fr11)play_buzzer(2,5,20);;
		  //lcd_puts(file.fname);
		  dir_status=START;
          
     	} 
   	   }
	    
	    buzzer_on();
		_delay_ms(50);
		buzzer_off();
		_delay_ms(150);
		
	   state=STATE1;
	  }
	  
	  
	  if(state==STATE1)
	  { 
	     if(schange==CHANGE)
		  {
		   sprintf(fpath,"BOOKS/%s",file.fname);
		   fr11=pf_open(fpath);
		   if(fr11)play_buzzer(5,5,20);
		   schange=NCHANGE;
		  }
		
	    //lcd_clrscr();
		//lcd_home();
		while(chk_button()!=PAUSE)
		{
		 
		  fr11=pf_read(&buf11,1,&bread);
          if(!bread) {state=STATE0; break;} 		
	
             //lcd_putc(buf11);
            print_braille_char(buf11);
		} 
	   
	   
	    buzzer_on();
		_delay_ms(50);
		buzzer_off();
		_delay_ms(150);
		
		state=STATE0;
	  }
	}
	

	
	
		
}

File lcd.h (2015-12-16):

#ifndef LCD_H
#define LCD_H
/*************************************************************************
 Title	:   C include file for the HD44780U LCD library (lcd.c)
 Author:    Peter Fleury <pfleury@gmx.ch>  http://jump.to/fleury
 File:	    $Id: lcd.h,v 1.13.2.2 2006/01/30 19:51:33 peter Exp $
 Software:  AVR-GCC 3.3
 Hardware:  any AVR device, memory mapped mode only for AT90S4414/8515/Mega
***************************************************************************/

/**
 @defgroup pfleury_lcd LCD library
 @code #include <lcd.h> @endcode
 
 @brief Basic routines for interfacing a HD44780U-based text LCD display

 Originally based on Volker Oth's LCD library,
 changed lcd_init(), added additional constants for lcd_command(), 
 added 4-bit I/O mode, improved and optimized code.
       
 Library can be operated in memory mapped mode (LCD_IO_MODE=0) or in 
 4-bit IO port mode (LCD_IO_MODE=1). 8-bit IO port mode not supported.

 Memory mapped mode compatible with Kanda STK200, but supports also 
 generation of R/W signal through A8 address line.
       
 @author Peter Fleury pfleury@gmx.ch http://jump.to/fleury
 
 @see The chapter <a href="http://homepage.sunrise.ch/mysunrise/peterfleury/avr-lcd44780.html" target="_blank">Interfacing a HD44780 Based LCD to an AVR</a>
      on my home page.

*/

/*@{*/

#if (__GNUC__ * 100 + __GNUC_MINOR__) < 303
#error "This library requires AVR-GCC 3.3 or later, update to newer AVR-GCC compiler !"
#endif

#include <inttypes.h>
#include <avr/pgmspace.h>

/** 
 *  @name  Definitions for MCU Clock Frequency
 *  Adapt the MCU clock frequency in Hz to your target. 
 */
#define XTAL 8000000              /**< clock frequency in Hz, used to calculate delay timer */


/**
 * @name  Definition for LCD controller type
 * Use 0 for HD44780 controller, change to 1 for displays with KS0073 controller.
 */
#define LCD_CONTROLLER_KS0073 0  /**< Use 0 for HD44780 controller, 1 for KS0073 controller */

/** 
 *  @name  Definitions for Display Size 
 *  Change these definitions to adapt setting to your display
 */
#define LCD_LINES           2    /**< number of visible lines of the display */
#define LCD_DISP_LENGTH    16     /**< visibles characters per line of the display */
#define LCD_LINE_LENGTH  0x40     /**< internal line length of the display    */
#define LCD_START_LINE1  0x00     /**< DDRAM address of first char of line 1 */
#define LCD_START_LINE2  0x40     /**< DDRAM address of first char of line 2 */
#define LCD_START_LINE3  0x14     /**< DDRAM address of first char of line 3 */
#define LCD_START_LINE4  0x54     /**< DDRAM address of first char of line 4 */
#define LCD_WRAP_LINES      0     /**< 0: no wrap, 1: wrap at end of visibile line */


#define LCD_IO_MODE      1         /**< 0: memory mapped mode, 1: IO port mode */
#if LCD_IO_MODE
/**
 *  @name Definitions for 4-bit IO mode
 *  Change LCD_PORT if you want to use a different port for the LCD pins.
 *
 *  The four LCD data lines and the three control lines RS, RW, E can be on the 
 *  same port or on different ports. 
 *  Change LCD_RS_PORT, LCD_RW_PORT, LCD_E_PORT if you want the control lines on
 *  different ports. 
 *
 *  Normally the four data lines should be mapped to bit 0..3 on one port, but it
 *  is possible to connect these data lines in different order or even on different
 *  ports by adapting the LCD_DATAx_PORT and LCD_DATAx_PIN definitions.
 *  
 */
#define LCD_PORT         PORTA       /**< port for the LCD lines   */
#define LCD_DATA0_PORT   LCD_PORT     /**< port for 4bit data bit 0 */
#define LCD_DATA1_PORT   LCD_PORT     /**< port for 4bit data bit 1 */
#define LCD_DATA2_PORT   LCD_PORT     /**< port for 4bit data bit 2 */
#define LCD_DATA3_PORT   LCD_PORT     /**< port for 4bit data bit 3 */
#define LCD_DATA0_PIN    4           /**< pin for 4bit data bit 0  */
#define LCD_DATA1_PIN    3            /**< pin for 4bit data bit 1  */
#define LCD_DATA2_PIN    2            /**< pin for 4bit data bit 2  */
#define LCD_DATA3_PIN    1
       /**< pin for 4bit data bit 3  */
#define LCD_RS_PORT      LCD_PORT     /**< port for RS line         */
#define LCD_RS_PIN       7        /**< pin  for RS line         */
#define LCD_RW_PORT      LCD_PORT     /**< port for RW line         */
#define LCD_RW_PIN       6
       /**< pin  for RW line         */
#define LCD_E_PORT       LCD_PORT     /**< port for Enable line     */
#define LCD_E_PIN        5         /**< pin  for Enable line     */

#elif defined(__AVR_AT90S4414__) || defined(__AVR_AT90S8515__) || defined(__AVR_ATmega64__) || \
      defined(__AVR_ATmega8515__)|| defined(__AVR_ATmega103__) || defined(__AVR_ATmega128__) || \
      defined(__AVR_ATmega161__) || defined(__AVR_ATmega162__)
/*
 *  memory mapped mode is only supported when the device has an external data memory interface
 */
#define LCD_IO_DATA      0xC000    /* A15=E=1, A14=RS=1                 */
#define LCD_IO_FUNCTION  0x8000    /* A15=E=1, A14=RS=0                 */
#define LCD_IO_READ      0x0100    /* A8 =R/W=1 (R/W: 1=Read, 0=Write   */
#else
#error "external data memory interface not available for this device, use 4-bit IO port mode"

#endif


/**
 *  @name Definitions for LCD command instructions
 *  The constants define the various LCD controller instructions which can be passed to the 
 *  function lcd_command(), see HD44780 data sheet for a complete description.
 */

/* instruction register bit positions, see HD44780U data sheet */
#define LCD_CLR               0      /* DB0: clear display                  */
#define LCD_HOME              1      /* DB1: return to home position        */
#define LCD_ENTRY_MODE        2      /* DB2: set entry mode                 */
#define LCD_ENTRY_INC         1      /*   DB1: 1=increment, 0=decrement     */
#define LCD_ENTRY_SHIFT       0      /*   DB2: 1=display shift on           */
#define LCD_ON                3      /* DB3: turn lcd/cursor on             */
#define LCD_ON_DISPLAY        2      /*   DB2: turn display on              */
#define LCD_ON_CURSOR         1      /*   DB1: turn cursor on               */
#define LCD_ON_BLINK          0      /*     DB0: blinking cursor ?          */
#define LCD_MOVE              4      /* DB4: move cursor/display            */
#define LCD_MOVE_DISP         3      /*   DB3: move display (0-> cursor) ?  */
#define LCD_MOVE_RIGHT        2      /*   DB2: move right (0-> left) ?      */
#define LCD_FUNCTION          5      /* DB5: function set                   */
#define LCD_FUNCTION_8BIT     4      /*   DB4: set 8BIT mode (0->4BIT mode) */
#define LCD_FUNCTION_2LINES   3      /*   DB3: two lines (0->one line)      */
#define LCD_FUNCTION_10DOTS   2      /*   DB2: 5x10 font (0->5x7 font)      */
#define LCD_CGRAM             6      /* DB6: set CG RAM address             */
#define LCD_DDRAM             7      /* DB7: set DD RAM address             */
#define LCD_BUSY              7      /* DB7: LCD is busy                    */
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
